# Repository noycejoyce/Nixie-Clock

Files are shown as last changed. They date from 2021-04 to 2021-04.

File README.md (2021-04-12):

# Noyce Joyce - Nixie Clock

## PCB design

The printed circuit board was designed in pre-released KiCAD 5.99 available at [nightly build](https://kicad-downloads.s3.cern.ch/index.html?prefix=windows/nightly/).

The core of the board is IoT Bluetooth chip from Nordic Semi nRF52832 which drives Nixie tubes IN-12 statically via nine shift registers.

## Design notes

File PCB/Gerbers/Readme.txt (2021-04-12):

I order Rigid Board with these parameters and files:

Name:               NJ_NIXIE_MAIN
Customer:           3Dsimo

PCB Parameters:
Type:               FR4
Number of layers:   2 
Final thickness:    2.0 mm
Copper thickness:   35um
Finish:             HASL Lead Free
Soldermask TOP:		Black
Soldermask BOT:		Black
Silkscreen TOP:		White
Silkscreen Bottom:  White
Dimensions:			170.0 x 70.0 mm

Input Files:
bot.gbr             Copper - BOTTOM side 
top.gbr             Copper - TOP side    
mill.gbr            Milling of PCB
plt.gbr             Silkscreen - TOP
plb.gbr             Silkscreen - BOTTOM
smb.gbr             Solder mask - BOTTOM side
smt.gbr             Solder mask - TOP side
npth.exc            Non plated drills
pth.exc             Plated drills
paste_top.gbr       Stencil TOP
paste_bottom.gbr    Stencil BOTTOM

Copper order:
TOP
BOTTOM 

Output testing:
Electrical testing: YES

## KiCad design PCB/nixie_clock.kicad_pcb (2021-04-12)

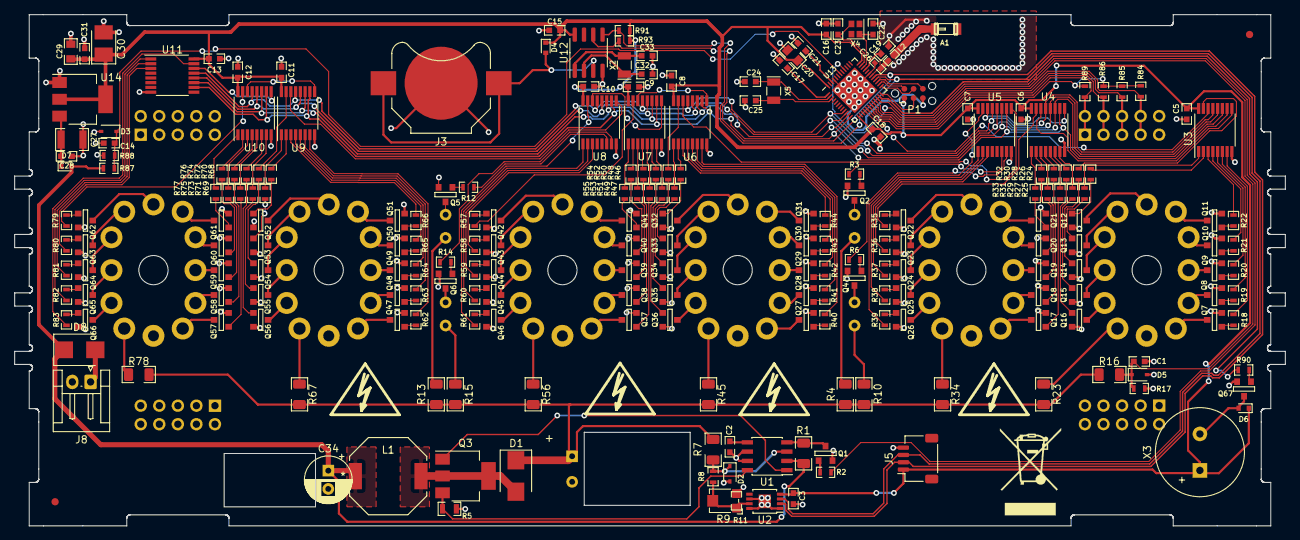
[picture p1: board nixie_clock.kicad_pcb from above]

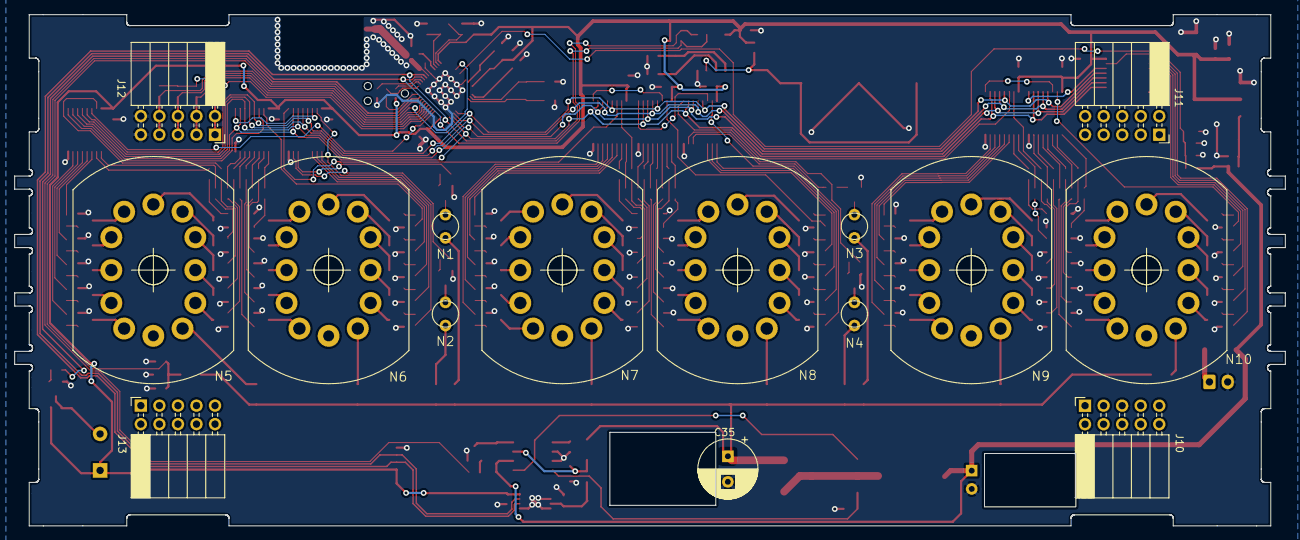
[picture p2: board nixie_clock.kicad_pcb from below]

Board: 2 copper layers, 174.0 x 70.0 mm, 247 parts (15 on the bottom side), 258 nets.

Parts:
A1: 2450AT18B100E; 2450A
C1, C2, C3, C5, C6, C7, C8, C9, C10, C11, C12, C13, C14, C17, C28, C31: 100n/50V; C_0603
C15, C16, C18, C21: 1u/25V; C_0603
C19: 100p; C_0603
C20, C29: 22u/6.3V; C_0805
C22, C23, C24, C25, C32, C33: 12p; C_0603
C26: 0.8p; C_0402
C27: 10u/35V; C_1210
C30: 100u/6.3V; CP_Tantalum_Case-B_EIA-3528-21_Reflow
C34: 100u/16V; CP_Radial_D6.3mm_P2.50mm
C35: 2.2u/400V; CP_Radial_D8.0mm_P3.50mm
D1, D8: ES2G; D_SMB_Standard
D2, D3, D5: MM3Z3V3T1G; D_SOD-323
D4, D6, D7: BAT42XV2; D_SOD-523
J1, J2: FiducialMark; AssemblyMark_1.0mm
J3: CR1225; BatteryHolder_Harwin_S8201R_1x12mm
J5: CONN_01X04; JST_SH_SM04B-SRSS-TB_1x04-1MP_P1.00mm_Horizontal
J8: CONN_01X02; JST_EH_S2B-EH_1x02_P2.50mm_Horizontal
J10, J11, J12, J13: CONN_02X05; PinSocket_2x05_P2.54mm_Horizontal
L1: SRU1038-101Y; L_Bourns_SRU1038
L2: 3.9nH; L_0402
N1, N2, N3, N4: IN-3; russian-nixies-IN-6
N5, N6, N7, N8, N9, N10: IN-12A; russian-nixies-IN-12
P1: TC2030-SWD; Tag-Connect_TC2030-IDC-NL
Q1, Q2, Q4, Q5, Q6, Q7, Q8, Q9, Q10, Q11, Q12, Q13, Q14, Q15, Q16, Q17, Q18, Q19, Q20, Q21, Q22, Q23, Q24, Q25, Q26, Q27, Q28, Q29, Q30, Q31, Q32, Q33, Q34, Q35, Q36, Q37, Q38, Q39, Q40, Q41, Q42, Q43, Q44, Q45, Q46, Q47, Q48, Q49, Q50, Q51, Q52, Q53, Q54, Q55, Q56, Q57, Q58, Q59, Q60, Q61, Q62, Q63, Q64, Q65, Q66, Q67: MMBTA42L; SOT-23
Q3: IPN50R1K4CE; SOT-223-3Lead_TabPin2
R1, R7, R16: 1M5; R_1206
R2, R3, R6, R12, R14, R18, R19, R20, R21, R22, R24, R25, R26, R27, R28, R29, R30, R31, R32, R33, R35, R36, R37, R38, R39, R40, R41, R42, R43, R44, R46, R47, R48, R49, R50, R51, R52, R53, R54, R55, R57, R58, R59, R60, R61, R62, R63, R64, R65, R66, R68, R69, R70, R71, R72, R73, R74, R75, R76, R77, R79, R80, R81, R82, R83: 1k; R_0603
R4, R10, R13, R15: 330k; R_1206
R5: 50mR; R_0805
R8, R88: 10k; R_0603
R9: 10k; Potentiometer_Bourns_TC33X_Vertical
R11: 0R; R_0603
R17: 22k; R_0603
R23, R34, R45, R56, R67, R78: 22k; R_1206
R84, R85, R86, R89: 1M; R_0603
R87: 383k; R_0603
R90, R91, R93: 4K7; R_0603
U1: MAX1771; SOIC-8_3.9x4.9mm_Pitch1.27mm
U2: MCP4561; MSOP-8-1EP_3x3mm_Pitch0.65mm
U3, U4, U5, U6, U7, U8, U9, U10, U11: 74HC595; TSSOP-16_4.4x5mm_Pitch0.65mm
U12: MCP7940N; SOIC-8_3.9x4.9mm_P1.27mm
U13: nRF52832; UQFN-48-1EP_6x6mm_Pitch0.4mm
U14: LD1117-3.3; SOT-223-3_TabPin2
X1, X7, X8, X9: High_Voltage; Symbol_HighVoltage_Type2_SilkScreenTop_VerySmall
X2, X5: LFXTAL009678; Crystal_SMD_MicroCrystal_CC7V-T1A-2pin_3.2x1.5mm
X3: SD1209T3-A1; Buzzer_12x9RM5.0
X4: XRCGB32M000; Crystal_SMD_2016-4pin_2.0x1.6mm
X6: Basket; WEEE-Logo_8.4x12mm_SilkScreen

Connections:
3V: C3.1, C5.2, C6.2, C7.2, C8.2, C9.2, C10.2, C11.2, C12.2, C13.2, C15.1, C16.1, C18.1, C20.1, C29.1, C30.1, C31.1, D4.1, D6.1, J5.1, P1.1, R91.1, R93.1, U2.4, U3.16, U4.16, U5.16, U6.16, U7.16, U8.16, U9.16, U10.16, U11.16, U12.8, U13.13, U13.36, U13.48, U14.2, X3.1
+12V: C34.1, D7.2, D8.1, L1.1, R1.1, R87.1, U1.2
/CLK: U3.11, U4.11, U5.11, U6.11, U7.11, U8.11, U9.11, U10.11, U11.11, U13.11
/DATA: U3.14, U13.16
/HIGH_VOLTAGE_EN: R2.1, U13.22
/MCU/BTN_MENU: J12.7, J12.8, R84.2, U13.21
/MCU/BTN_MINUS: J12.5, J12.6, R85.2, U13.20
/MCU/BTN_PLUS: J12.3, J12.4, R86.2, U13.19
/MCU/BTN_SET: J12.1, J12.2, R89.2, U13.18
/MCU/BUZZER: R90.2, U13.23
/MCU/COM_PUSH_BUTTON: R84.1, R85.1, R86.1, R89.1, U13.17
/MCU/RESET: P1.3, U13.24
/MCU/SWCLK: P1.4, U13.25
/MCU/SWDIO: P1.2, U13.26
/MCU/SWO: P1.6, U13.27
/MCU/V_VBUS: C14.1, D3.1, R87.2, R88.1, U13.42
/OE: U3.13, U4.13, U5.13, U6.13, U7.13, U8.13, U9.13, U10.13, U11.13, U13.9
/SCL: J5.2, R93.2, U2.2, U12.6, U13.29
/SDA: J5.3, R91.2, U2.3, U12.5, U13.28
/STCP: U3.12, U4.12, U5.12, U6.12, U7.12, U8.12, U9.12, U10.12, U11.12, U13.10
/V_HV: C1.1, D5.1, R16.2, R17.1, U13.40
/dualDisp2/DATA: U5.9, U6.14
/dualDisp2/Q6: R12.2, U8.6
/dualDisp2/Q7: R14.2, U8.7
/dualDisp3/DATA: U8.9, U9.14
/dualDisplay/Q6: R3.2, U5.6
/dualDisplay/Q7: R6.2, U5.7
/~RST: U3.10, U4.10, U5.10, U6.10, U7.10, U8.10, U9.10, U10.10, U11.10, U13.12
GND: C1.2, C2.2, C3.2, C5.1, C6.1, C7.1, C8.1, C9.1, C10.1, C11.1, C12.1, C13.1, C14.2, C15.2, C16.2, C17.2, C18.2, C19.2, C20.2, C21.2, C22.1, C23.1, C24.1, C25.1, C26.2, C27.2, C28.2, C29.2, C30.2, C31.2, C32.2, C33.2, C34.2, C35.2, D2.2, D3.2, D5.2, J3.2, J5.4, J8.2, J12.9, J12.10, P1.5, Q1.2, Q2.2, Q4.2, Q5.2, Q6.2, Q7.2, Q8.2, Q9.2, Q10.2, Q11.2, Q12.2, Q13.2, Q14.2, Q15.2, Q16.2, Q17.2, Q18.2, Q19.2, Q20.2, Q21.2, Q22.2, Q23.2, Q24.2, Q25.2, Q26.2, Q27.2, Q28.2, Q29.2, Q30.2, Q31.2, Q32.2, Q33.2, Q34.2, Q35.2, Q36.2, Q37.2, Q38.2, Q39.2, Q40.2, Q41.2, Q42.2, Q43.2, Q44.2, Q45.2, Q46.2, Q47.2, Q48.2, Q49.2, Q50.2, Q51.2, Q52.2, Q53.2, Q54.2, Q55.2, Q56.2, Q57.2, Q58.2, Q59.2, Q60.2, Q61.2, Q62.2, Q63.2, Q64.2, Q65.2, Q66.2, Q67.2, R5.2, R9.3, R11.2, R17.2, R88.2, U1.6, U1.7, U2.1, U2.6, U2.8, U2.9, U3.8, U4.8, U5.8, U6.8, U7.8, U8.8, U9.8, U10.8, U11.8, U12.4, U13.31, U13.45, U13.49, U14.1
unnamed: A1.1, L2.2
unnamed: C2.1, U1.5
unnamed: C17.1, U13.1
unnamed: C19.1, U13.33
unnamed: C21.1, U13.46
unnamed: C22.2, U13.34, X4.1
unnamed: C23.2, U13.35, X4.3
unnamed: C24.2, U13.2, X5.1
unnamed: C25.2, U13.3, X5.2
unnamed: C26.1, L2.1, U13.30
unnamed: C27.1, C28.1, D7.1, U14.3
unnamed: C32.1, U12.2, X2.1
unnamed: C33.1, U12.1, X2.2
unnamed: D1.2, L1.2, Q3.2
unnamed: D2.1, R7.2, R8.1, U1.3
unnamed: D4.2, J3.1, U12.3
unnamed: D6.2, Q67.3, X3.2
unnamed: D8.2, J8.1
unnamed: N1.A, R4.2
unnamed: N1.K, Q2.3
unnamed: N2.A, R10.2
unnamed: N2.K, Q4.3
unnamed: N3.A, R13.2
unnamed: N3.K, Q5.3
unnamed: N4.A, R15.2
unnamed: N4.K, Q6.3
unnamed: N5.0, Q16.3
unnamed: N5.1, Q7.3
unnamed: N5.2, Q8.3
unnamed: N5.3, Q9.3
unnamed: N5.4, Q10.3
unnamed: N5.5, Q11.3
unnamed: N5.6, Q12.3
unnamed: N5.7, Q13.3
unnamed: N5.8, Q14.3
unnamed: N5.9, Q15.3
unnamed: N5.A, R23.1
unnamed: N6.0, Q26.3
unnamed: N6.1, Q17.3
unnamed: N6.2, Q18.3
unnamed: N6.3, Q19.3
unnamed: N6.4, Q20.3
unnamed: N6.5, Q21.3
unnamed: N6.6, Q22.3
unnamed: N6.7, Q23.3
unnamed: N6.8, Q24.3
unnamed: N6.9, Q25.3
unnamed: N6.A, R34.1
unnamed: N7.0, Q36.3
unnamed: N7.1, Q27.3
unnamed: N7.2, Q28.3
unnamed: N7.3, Q29.3
unnamed: N7.4, Q30.3
unnamed: N7.5, Q31.3
unnamed: N7.6, Q32.3
unnamed: N7.7, Q33.3
unnamed: N7.8, Q34.3
unnamed: N7.9, Q35.3
unnamed: N7.A, R45.1
unnamed: N8.0, Q46.3
unnamed: N8.1, Q37.3
unnamed: N8.2, Q38.3
unnamed: N8.3, Q39.3
unnamed: N8.4, Q40.3
unnamed: N8.5, Q41.3
unnamed: N8.6, Q42.3
unnamed: N8.7, Q43.3
unnamed: N8.8, Q44.3
unnamed: N8.9, Q45.3
unnamed: N8.A, R56.1
unnamed: N9.0, Q56.3
unnamed: N9.1, Q47.3
unnamed: N9.2, Q48.3
unnamed: N9.3, Q49.3
unnamed: N9.4, Q50.3
unnamed: N9.5, Q51.3
unnamed: N9.6, Q52.3
unnamed: N9.7, Q53.3
unnamed: N9.8, Q54.3
unnamed: N9.9, Q55.3
unnamed: N9.A, R67.1
unnamed: N10.0, Q66.3
unnamed: N10.1, Q57.3
unnamed: N10.2, Q58.3
unnamed: N10.3, Q59.3
unnamed: N10.4, Q60.3
unnamed: N10.5, Q61.3
unnamed: N10.6, Q62.3
unnamed: N10.7, Q63.3
unnamed: N10.8, Q64.3
unnamed: N10.9, Q65.3
unnamed: N10.A, R78.1
unnamed: Q1.1, R2.2
unnamed: Q1.3, R1.2, U1.4
unnamed: Q2.1, R3.1
unnamed: Q3.1, U1.1
unnamed: Q3.3, R5.1, U1.8
unnamed: Q4.1, R6.1
unnamed: Q5.1, R12.1
unnamed: Q6.1, R14.1
unnamed: Q7.1, R18.1
unnamed: Q8.1, R19.1
unnamed: Q9.1, R20.1
unnamed: Q10.1, R21.1
unnamed: Q11.1, R22.1
unnamed: Q12.1, R24.1
unnamed: Q13.1, R25.1
unnamed: Q14.1, R26.1
unnamed: Q15.1, R27.1
unnamed: Q16.1, R28.1
unnamed: Q17.1, R29.1
unnamed: Q18.1, R30.1
unnamed: Q19.1, R31.1
unnamed: Q20.1, R32.1
unnamed: Q21.1, R33.1
unnamed: Q22.1, R35.1
unnamed: Q23.1, R36.1
unnamed: Q24.1, R37.1
unnamed: Q25.1, R38.1
unnamed: Q26.1, R39.1
unnamed: Q27.1, R40.1
unnamed: Q28.1, R41.1
unnamed: Q29.1, R42.1
unnamed: Q30.1, R43.1
unnamed: Q31.1, R44.1
unnamed: Q32.1, R46.1
unnamed: Q33.1, R47.1
unnamed: Q34.1, R48.1
unnamed: Q35.1, R49.1
unnamed: Q36.1, R50.1
unnamed: Q37.1, R51.1
unnamed: Q38.1, R52.1
unnamed: Q39.1, R53.1
unnamed: Q40.1, R54.1
unnamed: Q41.1, R55.1
unnamed: Q42.1, R57.1
unnamed: Q43.1, R58.1
unnamed: Q44.1, R59.1
unnamed: Q45.1, R60.1
unnamed: Q46.1, R61.1
unnamed: Q47.1, R62.1
unnamed: Q48.1, R63.1
unnamed: Q49.1, R64.1
unnamed: Q50.1, R65.1
unnamed: Q51.1, R66.1
unnamed: Q52.1, R68.1
unnamed: Q53.1, R69.1
unnamed: Q54.1, R70.1
unnamed: Q55.1, R71.1
unnamed: Q56.1, R72.1
unnamed: Q57.1, R73.1
unnamed: Q58.1, R74.1
unnamed: Q59.1, R75.1
unnamed: Q60.1, R76.1
unnamed: Q61.1, R77.1
unnamed: Q62.1, R79.1
unnamed: Q63.1, R80.1
unnamed: Q64.1, R81.1
unnamed: Q65.1, R82.1
unnamed: Q66.1, R83.1
unnamed: Q67.1, R90.1
unnamed: R8.2, R9.1, R9.2, R11.1, U2.7
unnamed: R18.2, U3.7
unnamed: R19.2, U3.6
unnamed: R20.2, U3.5
unnamed: R21.2, U3.4
unnamed: R22.2, U3.3
unnamed: R24.2, U3.2
unnamed: R25.2, U3.1
unnamed: R26.2, U3.15
unnamed: R27.2, U4.7
unnamed: R28.2, U4.6
unnamed: R29.2, U4.5
unnamed: R30.2, U4.4
unnamed: R31.2, U4.3
unnamed: R32.2, U4.2
unnamed: R33.2, U4.1
unnamed: R35.2, U4.15
unnamed: R36.2, U5.3
unnamed: R37.2, U5.2
unnamed: R38.2, U5.1
unnamed: R39.2, U5.15
unnamed: R40.2, U6.7
unnamed: R41.2, U6.6
unnamed: R42.2, U6.5
unnamed: R43.2, U6.4
unnamed: R44.2, U6.3
unnamed: R46.2, U6.2
unnamed: R47.2, U6.1
unnamed: R48.2, U6.15
unnamed: R49.2, U7.7
unnamed: R50.2, U7.6
unnamed: R51.2, U7.5
unnamed: R52.2, U7.4
unnamed: R53.2, U7.3
unnamed: R54.2, U7.2
unnamed: R55.2, U7.1
unnamed: R57.2, U7.15
unnamed: R58.2, U8.3
unnamed: R59.2, U8.2
unnamed: R60.2, U8.1
unnamed: R61.2, U8.15
unnamed: R62.2, U9.7
unnamed: R63.2, U9.6
unnamed: R64.2, U9.5
unnamed: R65.2, U9.4
unnamed: R66.2, U9.3
unnamed: R68.2, U9.2
unnamed: R69.2, U9.1
unnamed: R70.2, U9.15
unnamed: R71.2, U10.7
unnamed: R72.2, U10.6
unnamed: R73.2, U10.5
unnamed: R74.2, U10.4
unnamed: R75.2, U10.3
unnamed: R76.2, U10.2
unnamed: R77.2, U10.1
unnamed: R79.2, U10.15
unnamed: R80.2, U11.3
unnamed: R81.2, U11.2
unnamed: R82.2, U11.1
unnamed: R83.2, U11.15
unnamed: U3.9, U4.14
unnamed: U4.9, U5.14
unnamed: U6.9, U7.14
unnamed: U7.9, U8.14
unnamed: U10.9, U11.14
unnamed: U9.9, U10.14
VHV: C35.1, D1.1, R4.1, R7.1, R10.1, R13.1, R15.1, R16.1, R23.2, R34.2, R45.2, R56.2, R67.2, R78.2
